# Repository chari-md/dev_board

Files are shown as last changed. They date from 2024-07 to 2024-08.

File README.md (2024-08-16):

# STM32 Dev Board

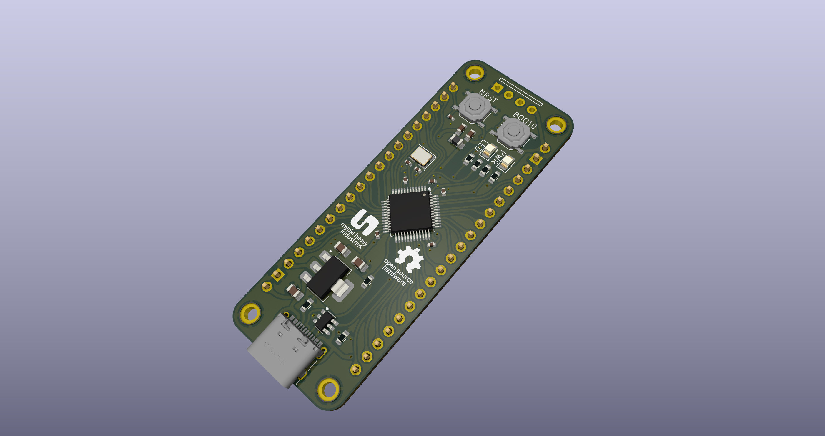
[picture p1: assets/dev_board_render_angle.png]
Board


This is a simple STM32 development board that I designed for my own use. It is based on the STM32F103C8T6 microcontroller. The design is inspired by the [Blue Pill][0] development board.

## Manufacturing

The board is designed to be manufactured using the [JLCPCB][1] assembly service. All the files required for manufacturing are in the `manufacturing` directory.

## Mechanical

The board is designed to be mounted in a 3D printed case. The case files are in the `case` directory or can be found on [Printables][2] and [Thingiverse][3].

The dimensions of the board are (L x W x H) 64mm x 24mm x 1.6mm.

The mounting holes are designed for [M2 ISO7380 screws][4].

[0]: https://stm32-base.org/boards/STM32F103C8T6-Blue-Pill.html
[1]: https://jlcpcb.com
[2]: https://www.thingiverse.com
[3]: https://www.printables.com
[4]: https://aliexpress.com/item/32810852732.html

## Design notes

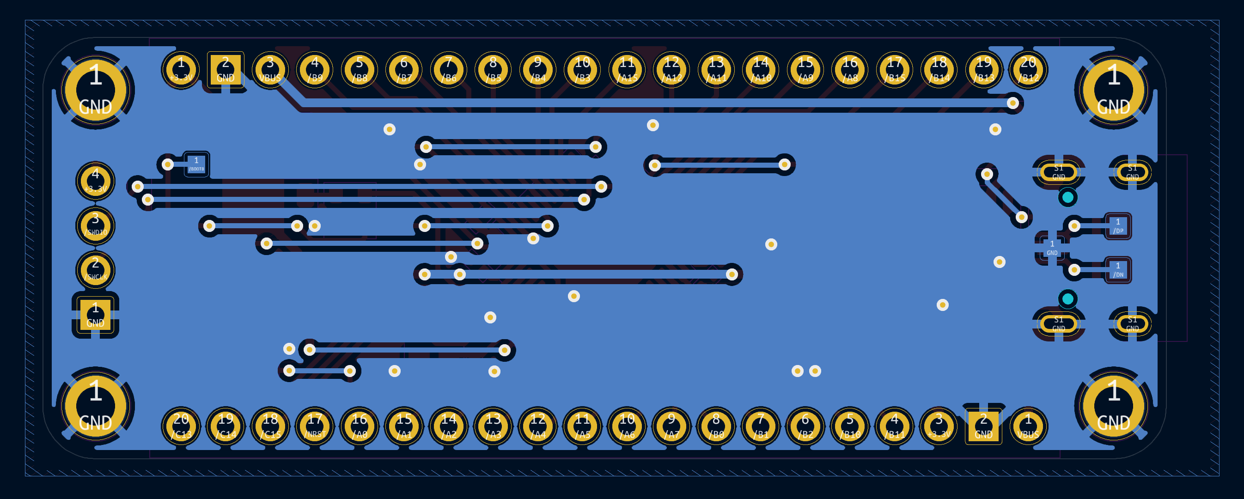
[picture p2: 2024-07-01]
assets/dev_board_bottom.png

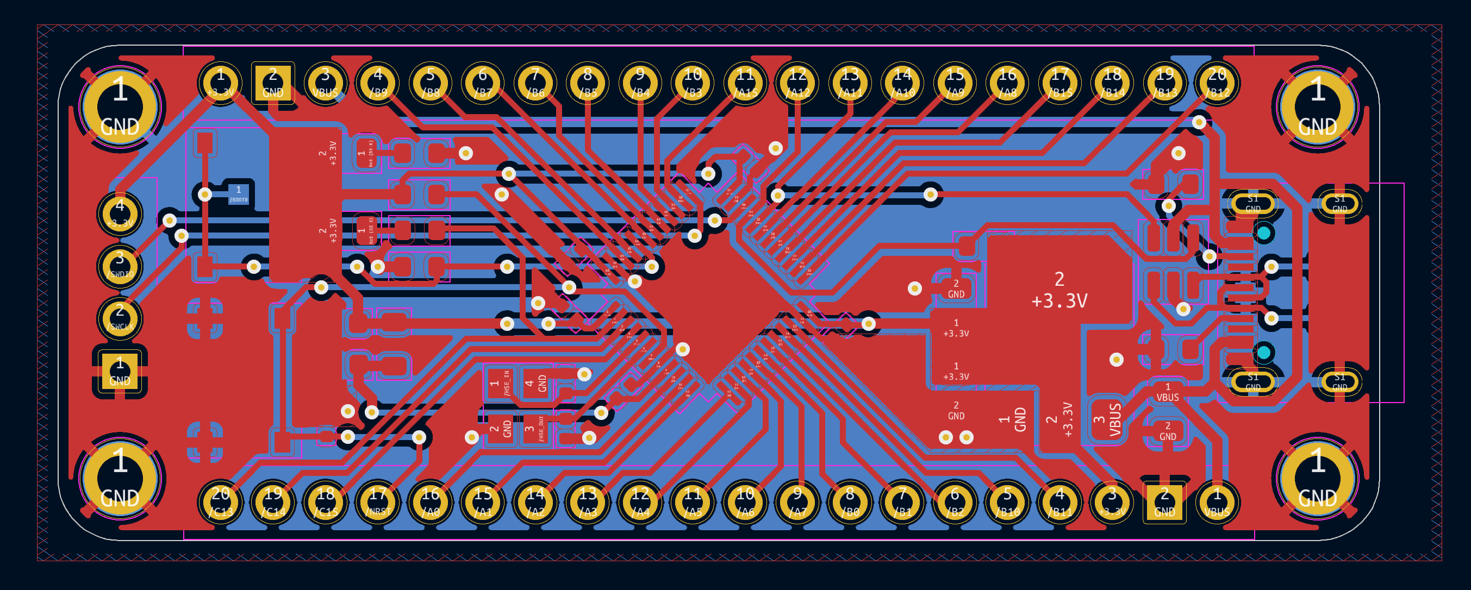
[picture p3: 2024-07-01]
assets/dev_board_top_bottom.png

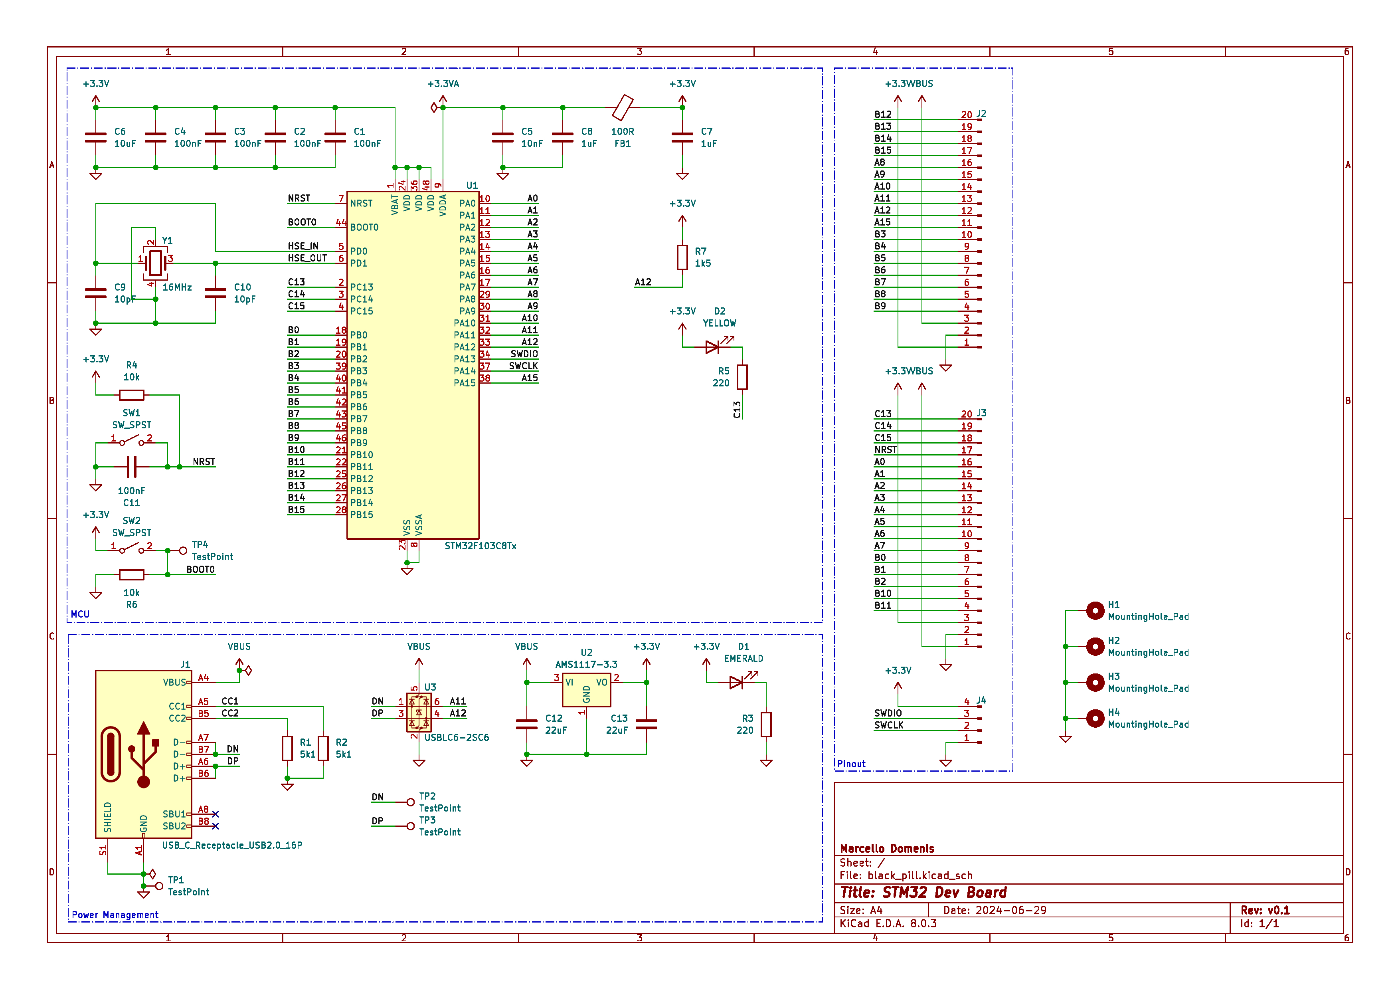
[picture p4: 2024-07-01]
assets/dev_board_sch.jpg

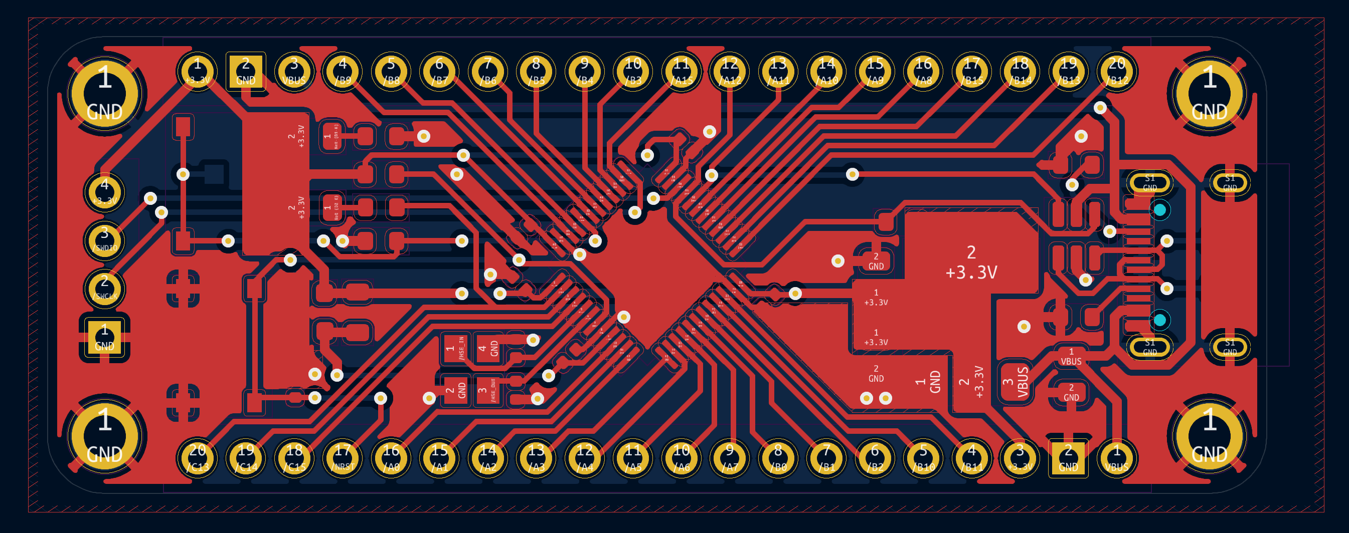
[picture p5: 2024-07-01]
assets/dev_baord_top.png

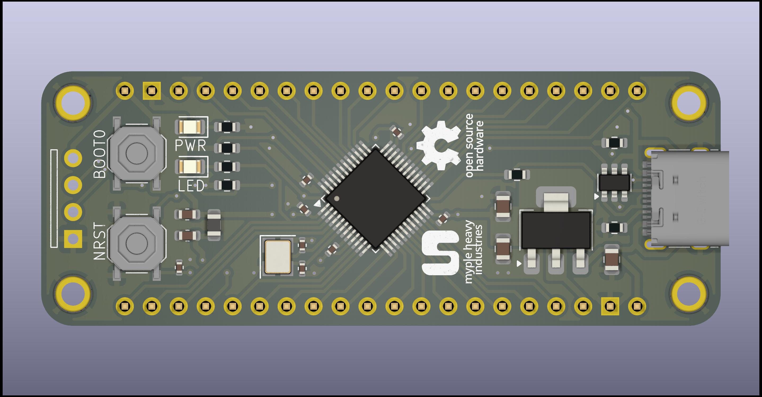
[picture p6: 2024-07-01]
assets/dev_board_render_top.jpg

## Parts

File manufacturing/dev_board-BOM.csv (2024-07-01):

Comment | Designator | Footprint | JLCPCB Part
100nF | C1,C2,C3,C4,C11 | Capacitor_SMD:C_0402_1005Metric | C1525
10nF | C5 | Capacitor_SMD:C_0402_1005Metric | C15195
10uF | C6 | Capacitor_SMD:C_0805_2012Metric | C15850
1uF | C7,C8 | Capacitor_SMD:C_0603_1608Metric | C15849
10pF | C9,C10 | Capacitor_SMD:C_0402_1005Metric | C32949
22uF | C12,C13 | Capacitor_SMD:C_0805_2012Metric | C45783
EMERALD | D1 | LED_SMD:LED_0805_2012Metric | C2297
YELLOW | D2 | LED_SMD:LED_0805_2012Metric | C2296
100R | FB1 | Inductor_SMD:L_0805_2012Metric | C1015
USB_C_Receptacle_USB2.0_16P | J1 | Connector_USB:USB_C_Receptacle_G-Switch_GT-USB-7010ASV | C2988369
5k1 | R1,R2 | Resistor_SMD:R_0603_1608Metric | C23186
220 | R3,R5 | Resistor_SMD:R_0603_1608Metric | C22962
10k | R4,R6 | Resistor_SMD:R_0603_1608Metric | C25804
1k5 | R7 | Resistor_SMD:R_0603_1608Metric | C22843
SW_SPST | SW1,SW2 | Button_Switch_SMD:SW_Push_1P1T_XKB_TS-1187A | C318884
STM32F103C8Tx | U1 | Package_QFP:LQFP-48_7x7mm_P0.5mm | C8734
AMS1117-3.3 | U2 | Package_TO_SOT_SMD:SOT-223-3_TabPin2 | C6186
USBLC6-2SC6 | U3 | Package_TO_SOT_SMD:SOT-23-6 | C7519
16MHz | Y1 | Crystal:Crystal_SMD_3225-4Pin_3.2x2.5mm | C13738

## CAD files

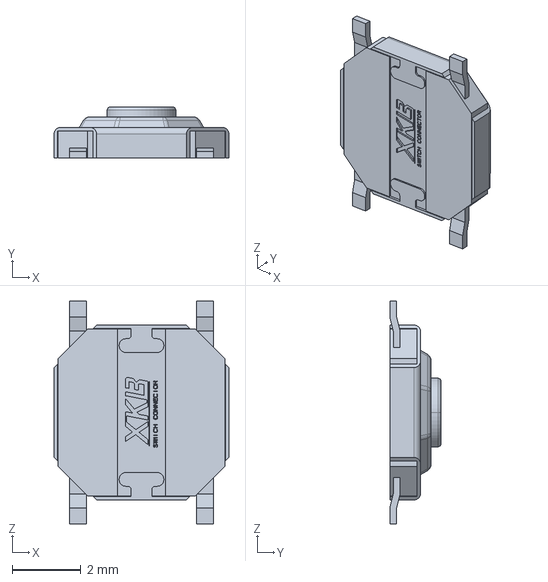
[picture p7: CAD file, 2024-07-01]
models/ts-1187a-x-a-x.stp
5.10 x 1.50 x 6.50 mm

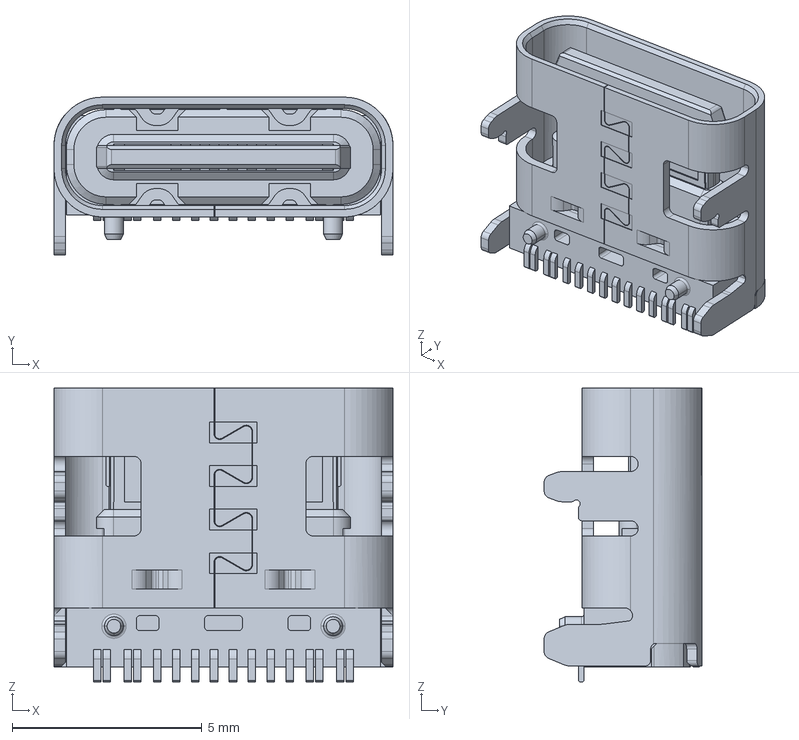
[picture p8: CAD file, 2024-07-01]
models/gt-usb-7010a.stp
8.94 x 4.16 x 7.75 mm

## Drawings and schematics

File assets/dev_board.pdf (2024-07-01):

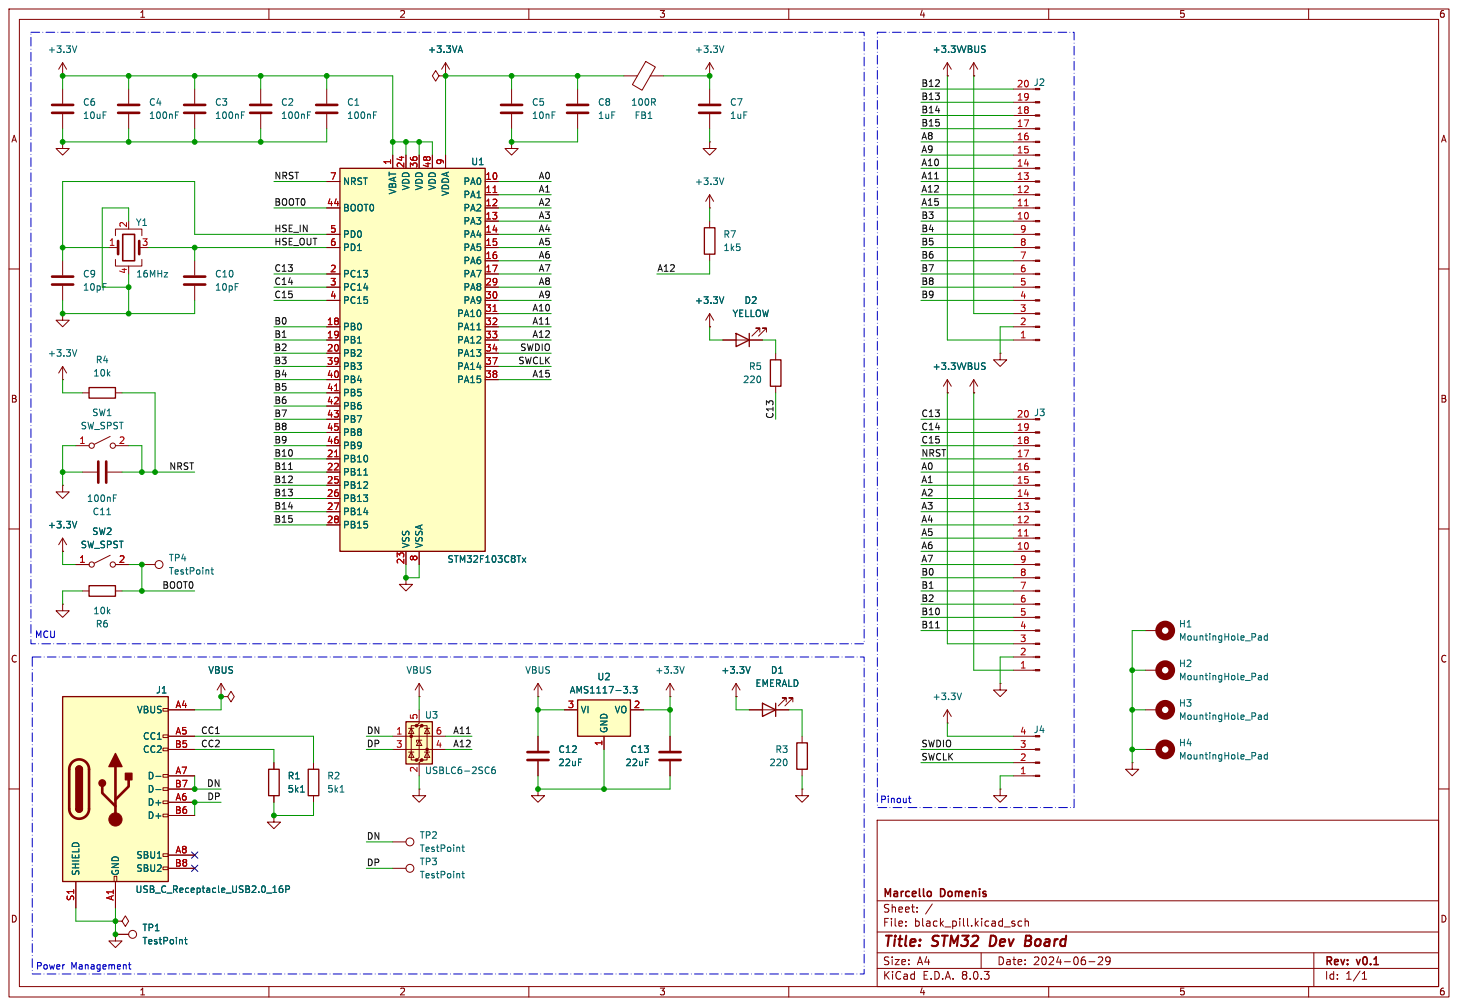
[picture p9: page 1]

Id: 1/1 Title: STM32 Dev Board

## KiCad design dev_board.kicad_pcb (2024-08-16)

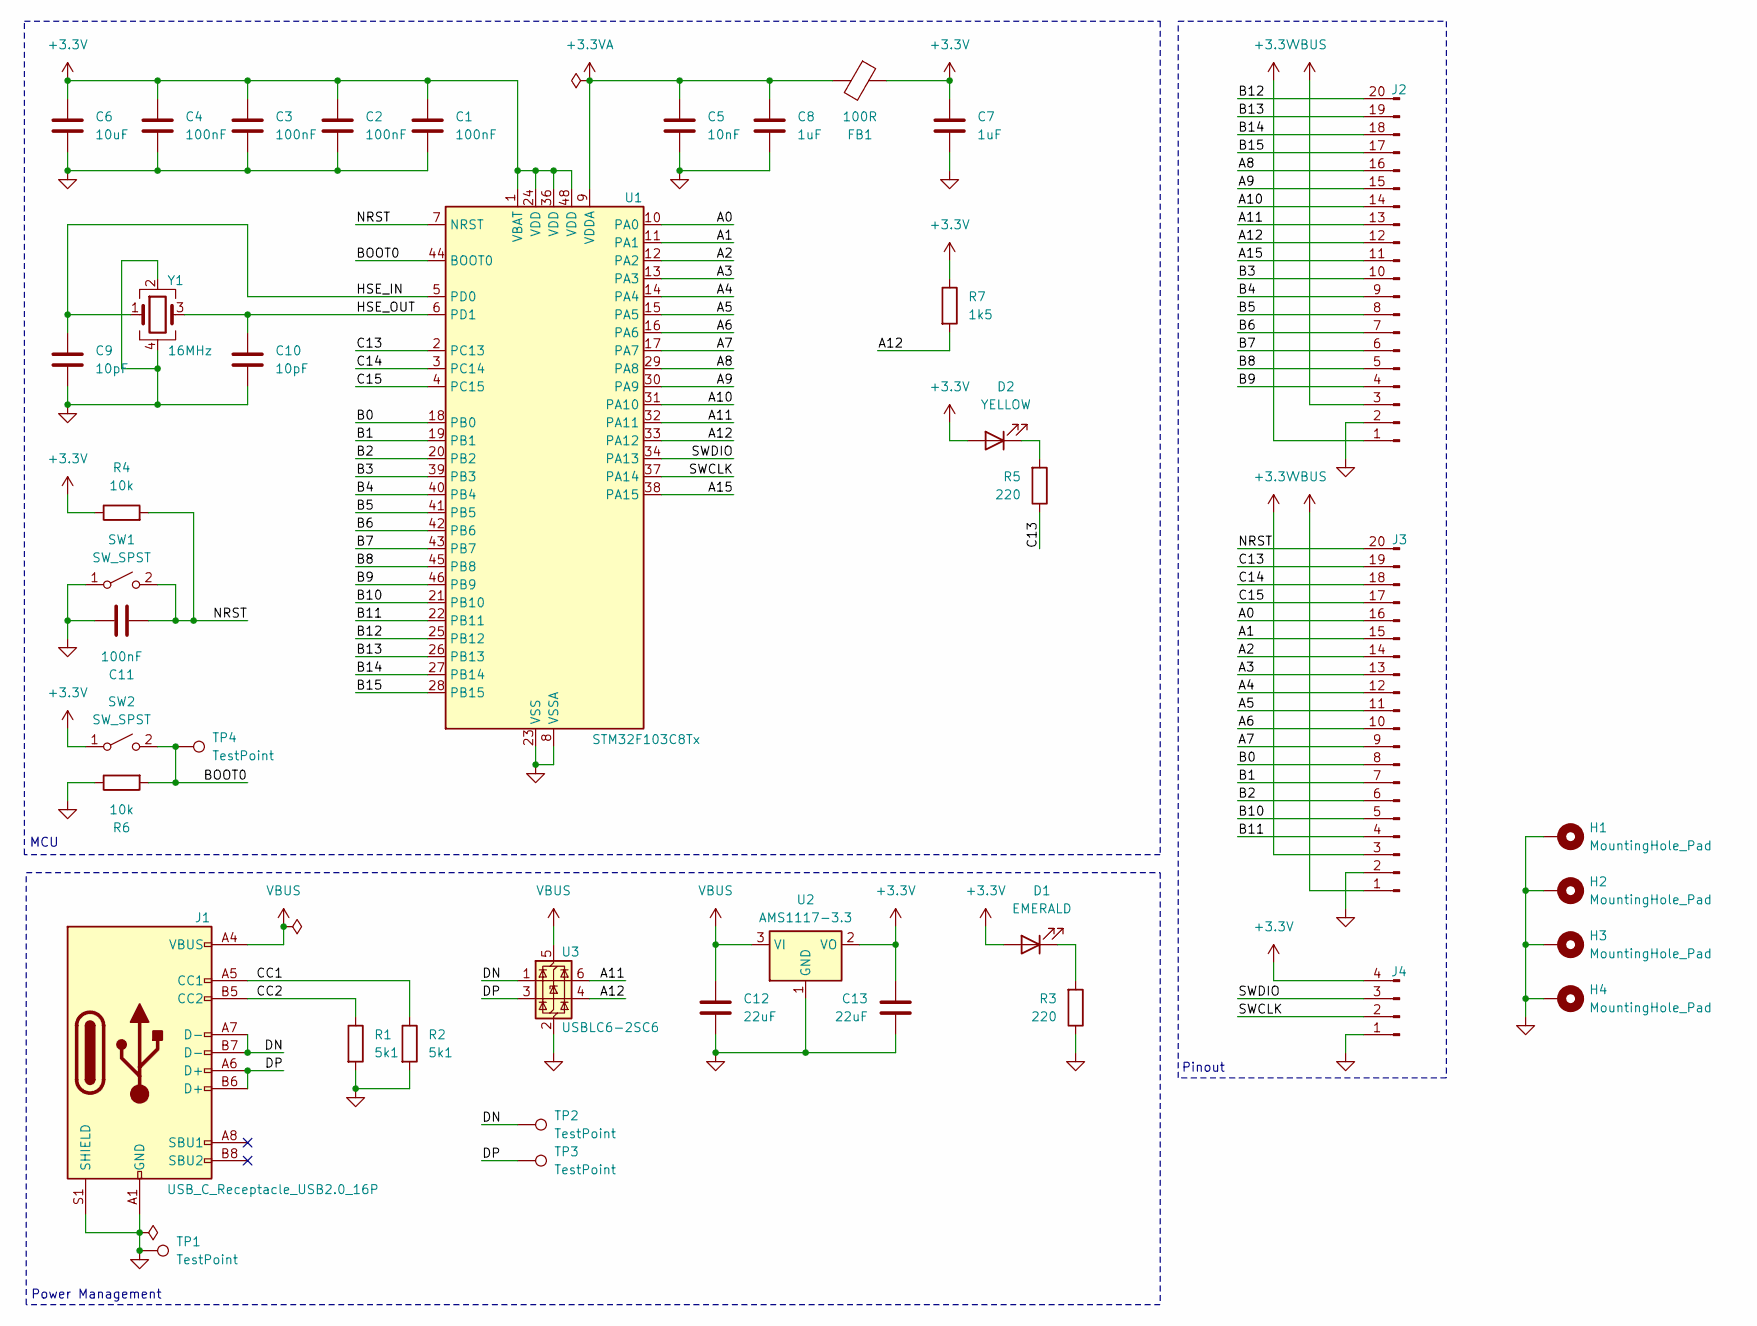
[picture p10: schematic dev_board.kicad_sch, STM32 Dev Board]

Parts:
C1, C2, C3, C4, C11: 100nF; C_0402_1005Metric
C5: 10nF; C_0402_1005Metric
C6: 10uF; C_0805_2012Metric
C7, C8: 1uF; C_0603_1608Metric
C9, C10: 10pF; C_0402_1005Metric
C12, C13: 22uF; C_0805_2012Metric
D1: EMERALD; LED_0805_2012Metric
D2: YELLOW; LED_0805_2012Metric
FB1: 100R; L_0805_2012Metric
H1, H2, H3, H4: MountingHole_Pad; MountingHole_2.2mm_M2_ISO7380_Pad
J1: USB_C_Receptacle_USB2.0_16P; USB_C_Receptacle_G-Switch_GT-USB-7010ASV
J2, J3: Conn_01x20_Pin; PinHeader_1x20_P2.54mm_Vertical
J4: Conn_01x04_Pin; PinHeader_1x04_P2.54mm_Vertical
R1, R2: 5k1; R_0603_1608Metric
R3, R5: 220; R_0603_1608Metric
R4, R6: 10k; R_0603_1608Metric
R7: 1k5; R_0603_1608Metric
SW1, SW2: SW_SPST; SW_Push_1P1T_XKB_TS-1187A
TP1, TP2, TP3, TP4: TestPoint; TestPoint_Pad_1.0x1.0mm
U1: STM32F103C8Tx; LQFP-48_7x7mm_P0.5mm
U2: AMS1117-3.3; SOT-223-3_TabPin2
U3: USBLC6-2SC6; SOT-23-6
Y1: 16MHz; Crystal_SMD_3225-4Pin_3.2x2.5mm

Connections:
+3.3V: C1.1, C2.1, C3.1, C4.1, C6.1, C7.1, C13.1, D1.2 (A), D2.2 (A), FB1.1, J2.1, J3.3, J4.4, R4.1, R7.1, SW2.1 (A), U1.1 (VBAT), U1.24 (VDD), U1.36 (VDD), U1.48 (VDD), U2.2 (VO)
+3.3VA: C5.1, C8.1, FB1.2, U1.9 (VDDA)
/A0: J3.16, U1.10 (PA0)
/A1: J3.15, U1.11 (PA1)
/A2: J3.14, U1.12 (PA2)
/A3: J3.13, U1.13 (PA3)
/A4: J3.12, U1.14 (PA4)
/A5: J3.11, U1.15 (PA5)
/A6: J3.10, U1.16 (PA6)
/A7: J3.9, U1.17 (PA7)
/A8: J2.16, U1.29 (PA8)
/A9: J2.15, U1.30 (PA9)
/A10: J2.14, U1.31 (PA10)
/A11: J2.13, U1.32 (PA11), U3.6 (I/O1)
/A12: J2.12, R7.2, U1.33 (PA12), U3.4 (I/O2)
/A15: J2.11, U1.38 (PA15)
/B0: J3.8, U1.18 (PB0)
/B1: J3.7, U1.19 (PB1)
/B2: J3.6, U1.20 (PB2)
/B3: J2.10, U1.39 (PB3)
/B4: J2.9, U1.40 (PB4)
/B5: J2.8, U1.41 (PB5)
/B6: J2.7, U1.42 (PB6)
/B7: J2.6, U1.43 (PB7)
/B8: J2.5, U1.45 (PB8)
/B9: J2.4, U1.46 (PB9)
/B10: J3.5, U1.21 (PB10)
/B11: J3.4, U1.22 (PB11)
/B12: J2.20, U1.25 (PB12)
/B13: J2.19, U1.26 (PB13)
/B14: J2.18, U1.27 (PB14)
/B15: J2.17, U1.28 (PB15)
/BOOT0: R6.2, SW2.2 (B), TP4.1, U1.44 (BOOT0)
/C13: J3.19, R5.1, U1.2 (PC13)
/C14: J3.18, U1.3 (PC14)
/C15: J3.17, U1.4 (PC15)
/CC1: J1.A5 (CC1), R2.1
/CC2: J1.B5 (CC2), R1.1
/DN: J1.A7 (D-), J1.B7 (D-), TP2.1, U3.1 (I/O1)
/DP: J1.A6 (D+), J1.B6 (D+), TP3.1, U3.3 (I/O2)
/HSE_IN: C9.1, U1.5 (PD0), Y1.1
/HSE_OUT: C10.1, U1.6 (PD1), Y1.3
/NRST: C11.1, J3.20, R4.2, SW1.2 (B), U1.7 (NRST)
/SWCLK: J4.2, U1.37 (PA14)
/SWDIO: J4.3, U1.34 (PA13)
GND: C1.2, C2.2, C3.2, C4.2, C5.2, C6.2, C7.2, C8.2, C9.2, C10.2, C11.2, C12.2, C13.2, H1.1, H2.1, H3.1, H4.1, J1.A1 (GND), J1.A12 (GND), J1.B1 (GND), J1.B12 (GND), J1.S1 (SHIELD), J2.2, J3.2, J4.1, R1.2, R2.2, R3.1, R6.1, SW1.1 (A), TP1.1, U1.8 (VSSA), U1.23 (VSS), U1.35 (VSS), U1.47 (VSS), U2.1 (GND), U3.2 (GND), Y1.2, Y1.4
unnamed: D1.1 (K), R3.2
unnamed: D2.1 (K), R5.2
VBUS: C12.1, J1.A4 (VBUS), J1.A9 (VBUS), J1.B4 (VBUS), J1.B9 (VBUS), J2.3, J3.1, U2.3 (VI), U3.5 (VBUS)

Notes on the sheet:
Pinout
Power Management
MCU

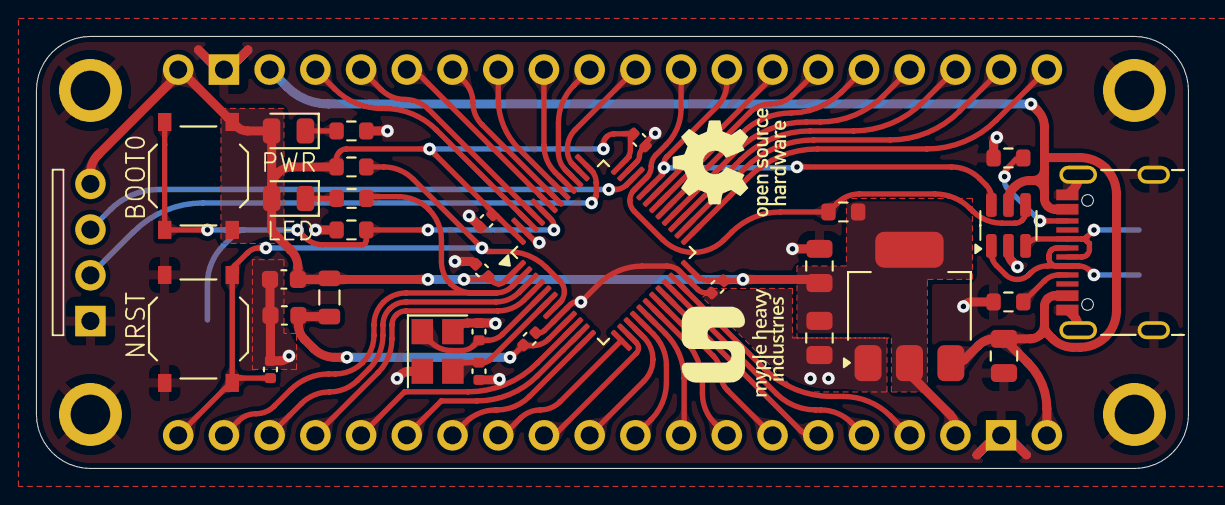
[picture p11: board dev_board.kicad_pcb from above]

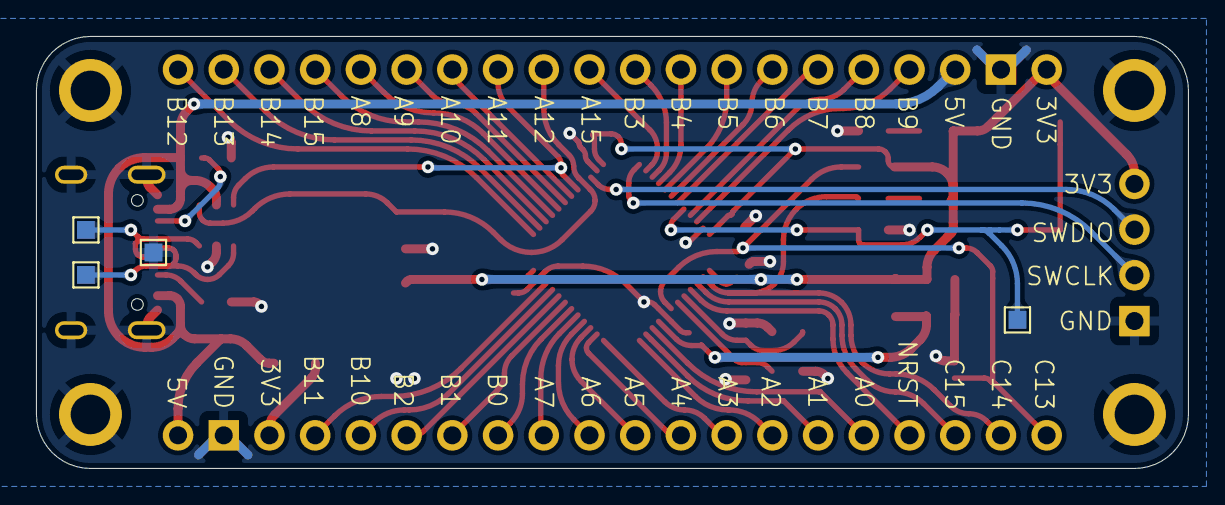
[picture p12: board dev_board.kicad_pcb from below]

Board: 2 copper layers, 64.0 x 24.0 mm, 41 parts (4 on the bottom side), 49 nets.

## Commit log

2024-07-01 init commit
    [dev_board-BOM.csv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]
2024-07-03 opt: zone fills and remove some vias after feedback
    [dev_board-B_Cu.gbr, dev_board-B_Mask.gbr, dev_board-B_Paste.gbr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]
2024-08-16 feat: add tear drops
    [dev_board.kicad_pcb]
2024-08-16 feat: round tracks
    [dev_board.kicad_pcb]
